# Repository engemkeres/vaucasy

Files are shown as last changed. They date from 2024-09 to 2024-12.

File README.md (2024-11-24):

# vaucasy
vaucasy is a split, ergonomic mechanical keyboard with a pair of OLEDs, rotary encoders and a trackball. It features a 4x7 staggered ortho layout on both halves.

The MCU chosen for this project was an STM32F401RET6, because I was familiar with STM32s F4 series.

[**QMK firmware**](https://github.com/engemkeres/qmk_firmware/tree/master/keyboards/vaucasy)

**Own firmware** with the support of ST's HAL library: [in progress](https://github.com/engemkeres/vaucasy_firmware)





**JCLPCB order preview:**

Right:
top_11_11_2024, 2_26_26 PM
bottom_11_11_2024, 2_26_26 PM

Left:
top_11_11_2024, 2_27_43 PM
bottom_11_11_2024, 2_27_43 PM

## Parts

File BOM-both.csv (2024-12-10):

Reference | Value | Datasheet | Footprint | Qty | DNP | JLCPCB part#
C1,C2,C3,C4,C5,C7,C13,C14,C15,C16,C17 | 100n | ~ | Capacitor_SMD:C_0402_1005Metric | 11 |  | C1525
C6 | 10u | ~ | Capacitor_SMD:C_0603_1608Metric | 1 |  | C19702
C8,C9 | 1u | ~ | Capacitor_SMD:C_0402_1005Metric | 2 |  | C52923
C10,C11 | 8p | ~ | Capacitor_SMD:C_0402_1005Metric | 2 |  | C1578
C12 | 4.7uF | ~ | Capacitor_SMD:C_0603_1608Metric | 1 |  | C19666
D1,D2,D3,D4,D5,D6,D7,D8,D9,D10,D11,D12,D13,D14,D15,D16,D17,D18,D19,D20,D21,D22,D23,D24,D25,D26,D27,D28,D29,D30,D31,D33 | Diode |  | ScottoKeebs_Components:Diode_SOD-123 | 32 |  | C7420318
F1 | 500mA | ~ | Fuse:Fuse_1206_3216Metric | 1 |  | C210357
J1 | USB_C | https://www.usb.org/sites/default/files/documents/usb_type-c.zip | Connector_USB:USB_C_Receptacle_HRO_TYPE-C-31-M-12 | 1 |  | C165948
J2 | OLED_128x32 |  | ScottoKeebs_Components:OLED_128x32 | 1 |  | C5248081
J4 | Trackball | ~ | Connector_PinHeader_2.54mm:PinHeader_1x05_P2.54mm_Vertical | 1
J5 | HC-05 BT | ~ | Connector_PinSocket_2.54mm:PinSocket_1x06_P2.54mm_Vertical | 1
J6 | DEBUG | ~ | Connector_PinHeader_2.54mm:PinHeader_1x04_P2.54mm_Vertical | 1
R1,R6,R7,R8 | 10k | ~ | Resistor_SMD:R_0402_1005Metric | 4 |  | C25744
R2 | 100R | ~ | Resistor_SMD:R_0402_1005Metric | 1 |  | C25076
R3,R4 | 5.1k | ~ | Resistor_SMD:R_0402_1005Metric | 2 |  | C25905
R9,R10,R13,R14 | 4.7k | ~ | Resistor_SMD:R_0402_1005Metric | 4 |  | C25900
S1,S2,S3,S4,S5,S6,S7,S8,S9,S10,S11,S12,S13,S14,S15,S16,S17,S18,S19,S20,S21,S22,S23,S24,S25,S26,S27,S28,S29,S30,S31 | Keyswitch | ~ | ScottoKeebs_Hotswap:Hotswap_Choc_V1V2_1.00u | 31
SW1 | SW_SPDT | ~ | Button_Switch_SMD:SW_SPDT_PCM12 | 1 |  | C221841
SW2 | SW_Push | ~ | ScottoKeebs_Components:Button_TL3342 | 1 |  | C115351
SW3 | RotaryEncoder_Switch | ~ | Rotary_Encoder:RotaryEncoder_Alps_EC11E-Switch_Vertical_H20mm | 1 |  | C470788
U1 | STM32F401RET6 | https://www.st.com/resource/en/datasheet/stm32f401re.pdf | Package_QFP:LQFP-64_10x10mm_P0.5mm | 1 |  | C116978
U2 | USBLC6-2SC6 | https://www.st.com/resource/en/datasheet/usblc6-2.pdf | Package_TO_SOT_SMD:SOT-23-6 | 1 |  | C2827654
U3 | XC6206 | https://www.torexsemi.com/file/xc6206/XC6206.pdf | Package_TO_SOT_SMD:SOT-23-3 | 1 |  | C5446
U4 | TRRS |  | ScottoKeebs_Components:TRRS_PJ-320A | 1 |  | C22459514
Y1 | 8MHz | ~ | Crystal:Crystal_SMD_3225-4Pin_3.2x2.5mm | 1 |  | C7275083

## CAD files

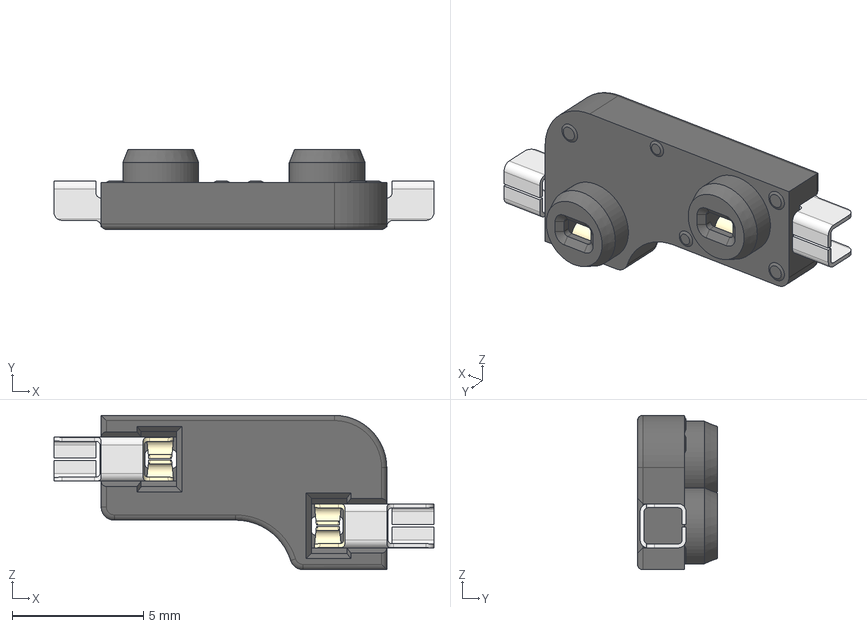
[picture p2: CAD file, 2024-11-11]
vaucasy_left/MX_V2/3D/MX-Hotswap-Socket.step
14.5 x 3.05 x 5.89 mm

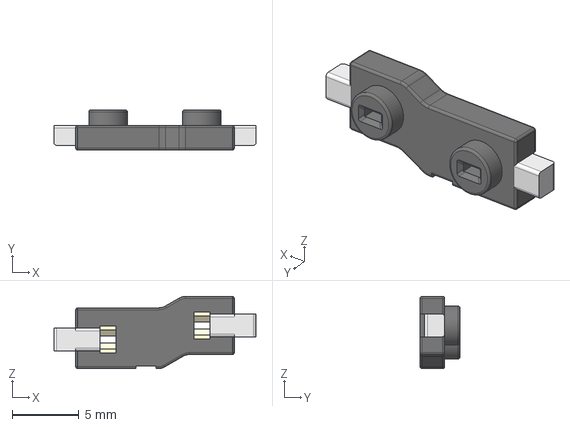
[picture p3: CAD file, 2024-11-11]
vaucasy_left/MX_V2/3D/Gateron-KS33-Socket.step
15.1 x 3.00 x 5.40 mm

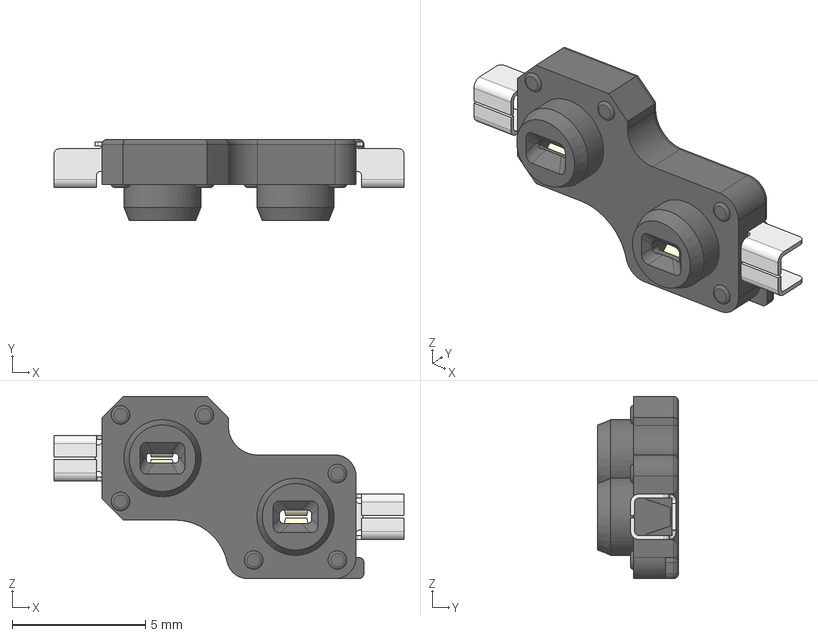
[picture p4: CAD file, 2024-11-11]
vaucasy_left/MX_V2/3D/Kailh-Choc-Socket-CPG135001S30.step
13.1 x 3.05 x 6.85 mm
Insert 2
Insert 1

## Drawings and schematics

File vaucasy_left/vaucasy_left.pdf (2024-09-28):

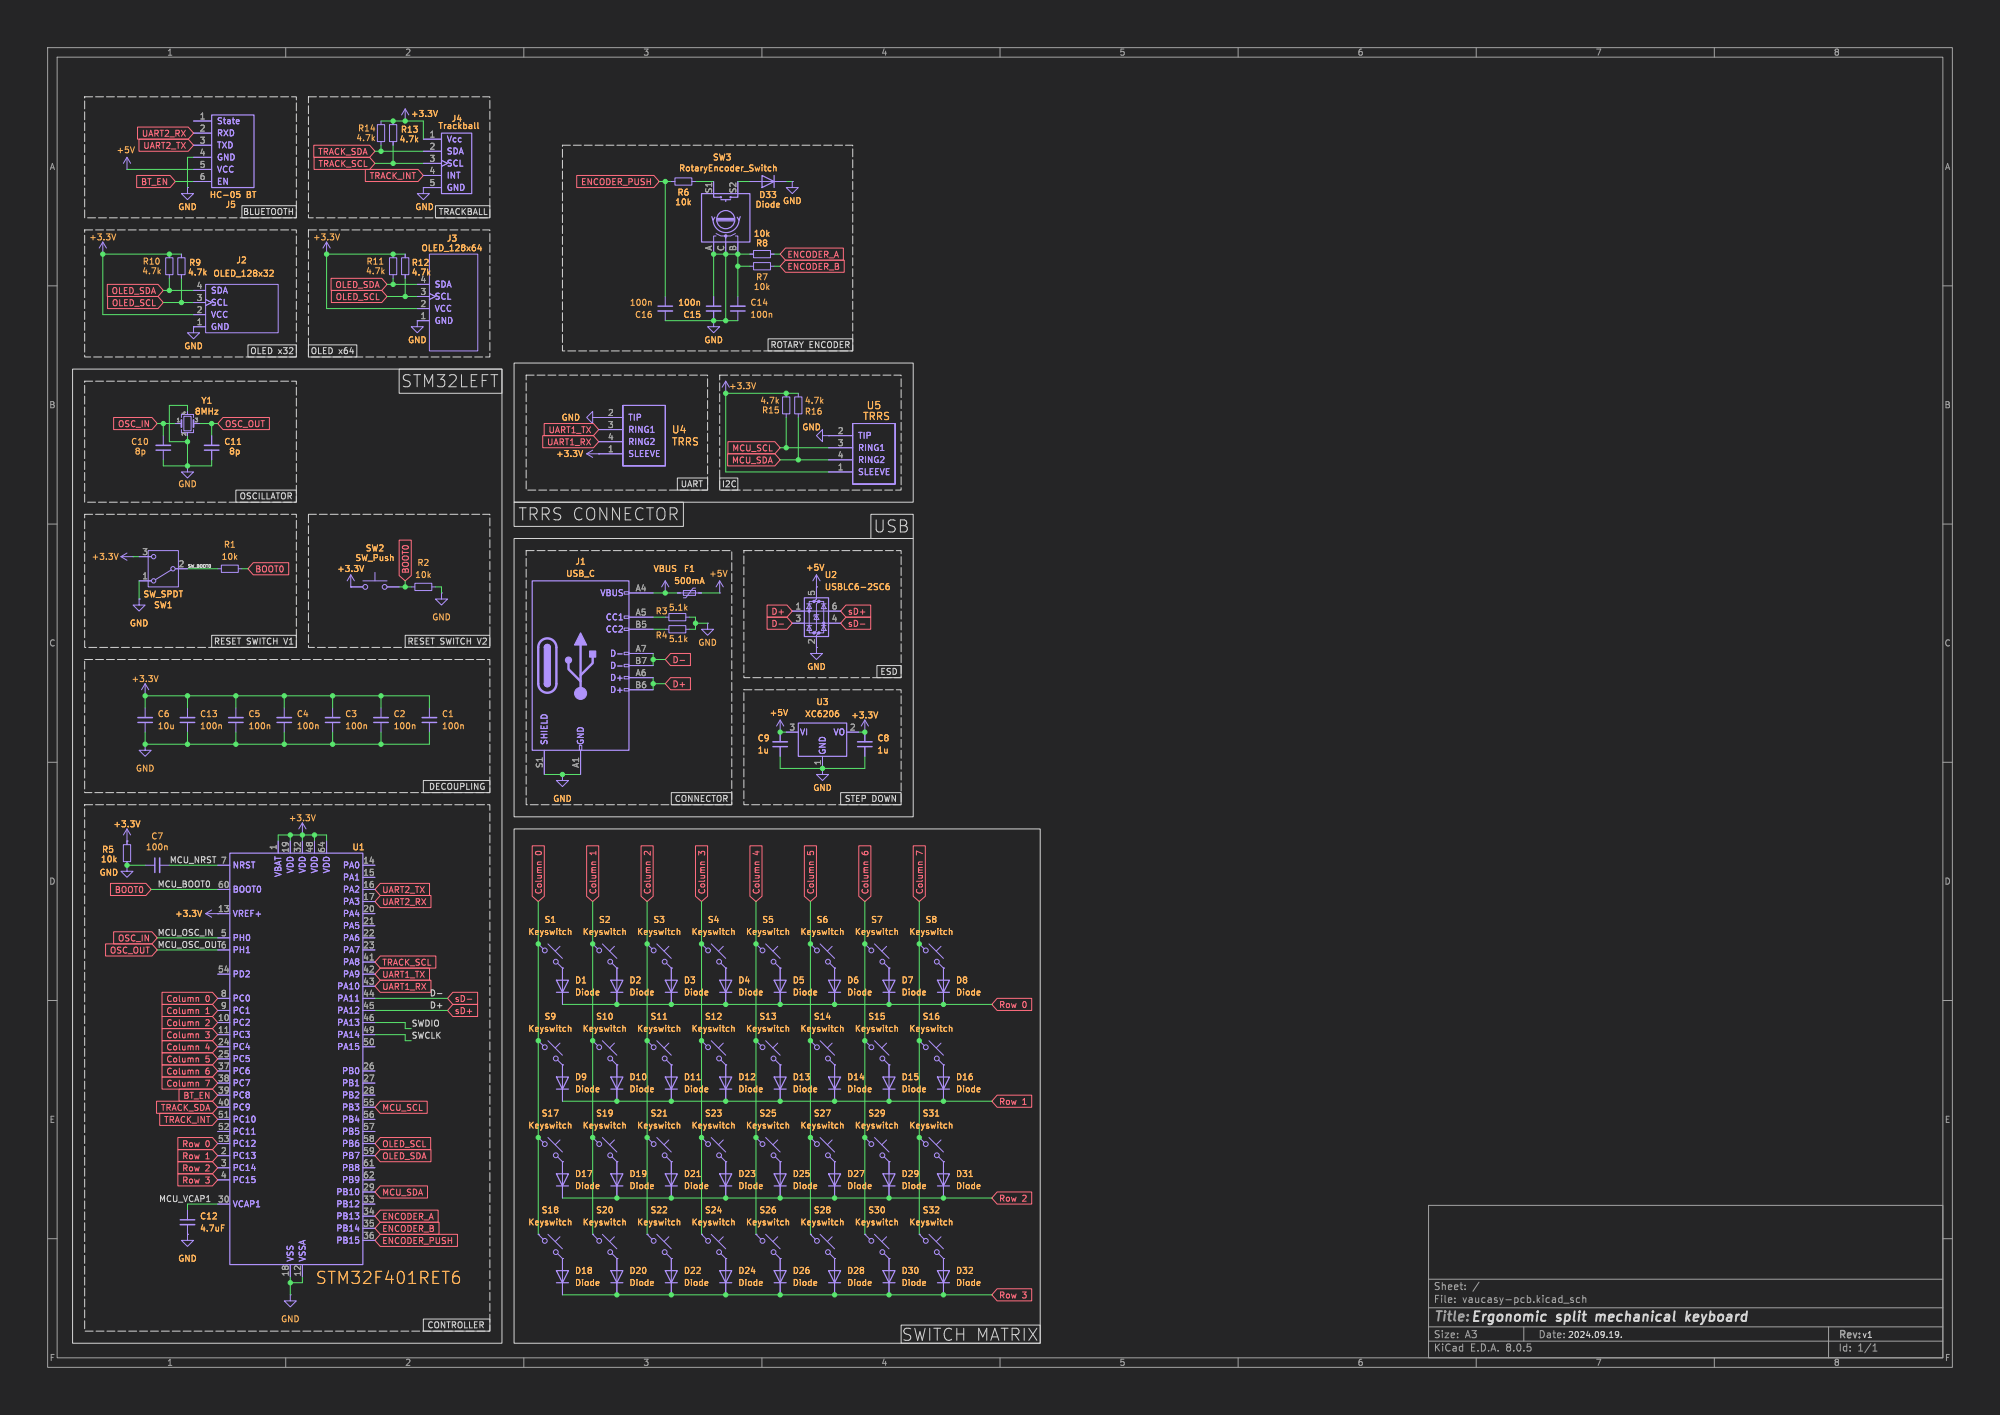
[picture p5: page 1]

J3 OLED_128x64 GND 1 VCC 2 SCL 3 SDA 4 +3.3V R13

Id: 1/1 Title: File: vaucasy-pcb.kicad_sch Sheet: / D9 Diode C6

D11 DiodeS12 Keyswitch D12 Diode D4 Diode D3 Diode D1 Diode

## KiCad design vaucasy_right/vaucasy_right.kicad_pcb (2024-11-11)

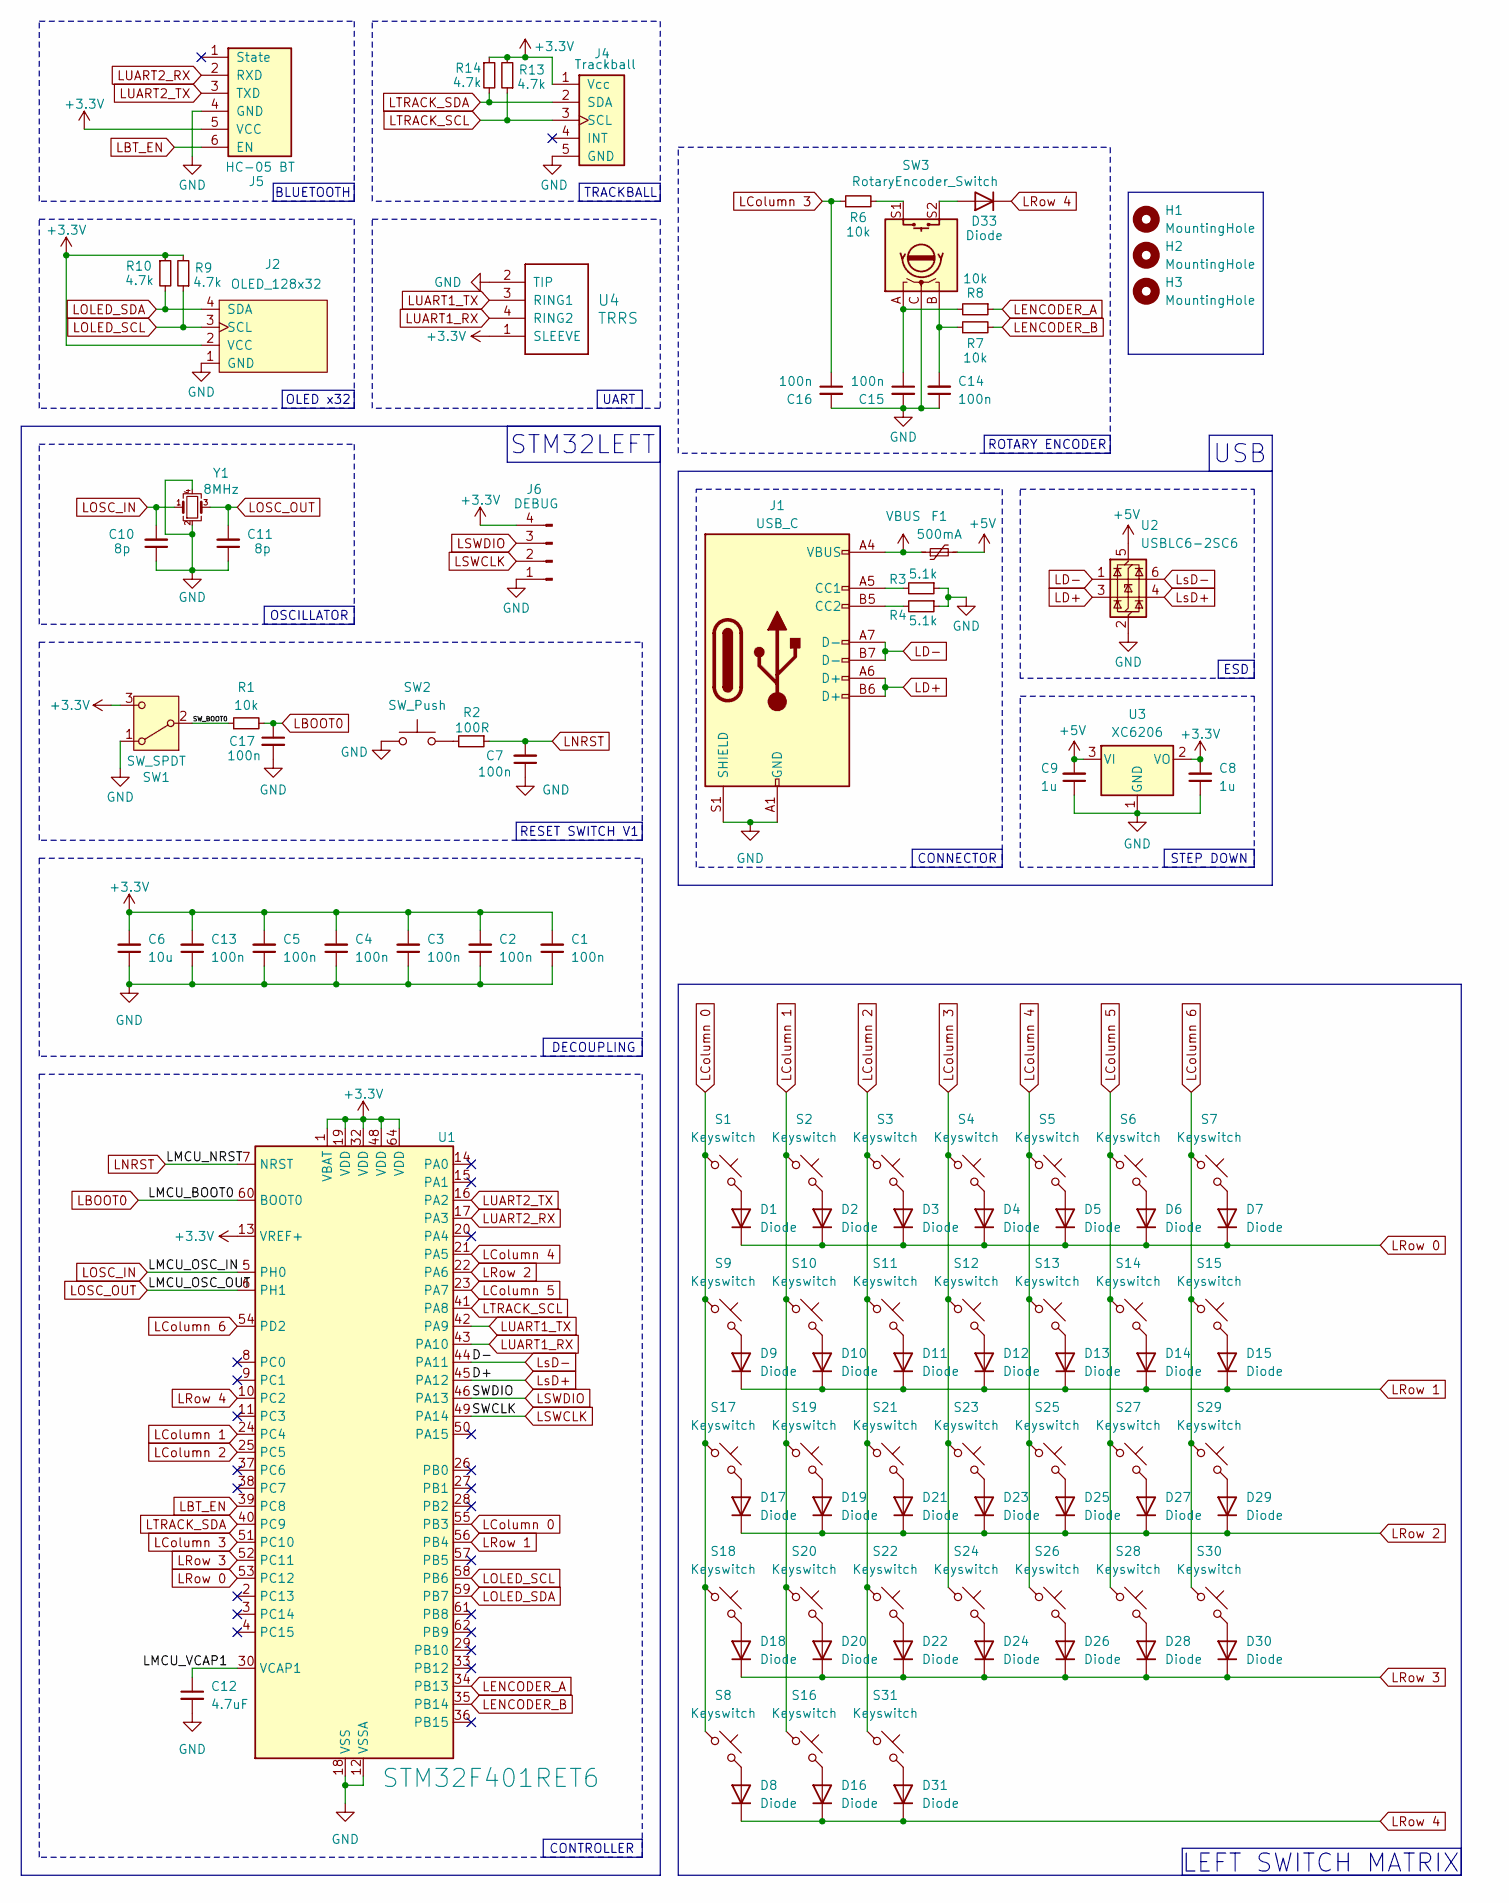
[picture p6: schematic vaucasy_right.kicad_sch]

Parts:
C1, C2, C3, C4, C5, C7, C13, C14, C15, C16, C17: 100n; C_0402_1005Metric
C6: 10u; C_0603_1608Metric
C8, C9: 1u; C_0402_1005Metric
C10, C11: 8p; C_0402_1005Metric
C12: 4.7uF; C_0603_1608Metric
D1, D2, D3, D4, D5, D6, D7, D8, D9, D10, D11, D12, D13, D14, D15, D16, D17, D18, D19, D20, D21, D22, D23, D24, D25, D26, D27, D28, D29, D30, D31, D33: Diode; Diode_SOD-123
F1: 500mA; Fuse_0603_1608Metric
H1, H2, H3: MountingHole; MountingHole_2.2mm_M2
J1: USB_C; USB_C_Receptacle_HRO_TYPE-C-31-M-12
J2: OLED_128x32
J4: Trackball; PinHeader_1x05_P2.54mm_Vertical
J5: HC-05 BT; PinSocket_1x06_P2.54mm_Vertical
J6: DEBUG; PinHeader_1x04_P2.54mm_Vertical
R1, R6, R7, R8: 10k; R_0402_1005Metric
R2: 100R; R_0402_1005Metric
R3, R4: 5.1k; R_0402_1005Metric
R9, R10, R13, R14: 4.7k; R_0402_1005Metric
S1, S2, S3, S4, S5, S6, S7, S8, S9, S10, S11, S12, S13, S14, S15, S16, S17, S18, S19, S20, S21, S22, S23, S24, S25, S26, S27, S28, S29, S30, S31: Keyswitch; Hotswap_Choc_V1V2_1.00u
SW1: SW_SPDT; SW_SPDT_PCM12
SW2: SW_Push; Button_TL3342
SW3: RotaryEncoder_Switch; RotaryEncoder_Alps_EC11E-Switch_Vertical_H20mm
U1: STM32F401RET6; LQFP-64_10x10mm_P0.5mm
U2: USBLC6-2SC6; SOT-23-6
U3: XC6206; SOT-23-3
U4: TRRS; TRRS_PJ-320A
Y1: 8MHz; Crystal_SMD_3225-4Pin_3.2x2.5mm

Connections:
+3.3V: C1.2, C2.2, C3.2, C4.2, C5.2, C6.2, C8.2, C13.2, J2.2 (VCC), J4.1 (Vcc), J5.5 (VCC), J6.4, R9.2, R10.1, R13.2, R14.1, SW1.3 (C), U1.1 (VBAT), U1.13 (VREF+), U1.19 (VDD), U1.32 (VDD), U1.48 (VDD), U1.64 (VDD), U3.2 (VO), U4.1 (SLEEVE)
+5V: C9.2, F1.2, U2.5 (VBUS), U3.3 (VI)
/LMCU_VCAP1: C12.1, U1.30 (VCAP1)
/SW_BOOT0: R1.1, SW1.2 (B)
GND: C1.1, C2.1, C3.1, C4.1, C5.1, C6.1, C7.1, C8.1, C9.1, C10.1, C11.1, C12.2, C13.1, C14.1, C15.2, C16.2, C17.2, J1.A1 (GND), J1.A12 (GND), J1.B1 (GND), J1.B12 (GND), J1.S1 (SHIELD), J2.1 (GND), J4.5 (GND), J5.4 (GND), J6.1, R3.1, R4.1, SW1.1 (A), SW2.1, SW3.C, U1.12 (VSSA), U1.18 (VSS), U1.31 (VSS), U1.47 (VSS), U1.63 (VSS), U2.2 (GND), U3.1 (GND), U4.2 (TIP), Y1.2, Y1.4
LBOOT0: C17.1, R1.2, U1.60 (BOOT0)
LBT_EN: J5.6 (EN), U1.39 (PC8)
LColumn 0: S1.1, S8.1, S9.1, S17.1, S18.1, U1.55 (PB3)
LColumn 1: S2.1, S10.1, S16.1, S19.1, S20.1, U1.24 (PC4)
LColumn 2: S3.1, S11.1, S21.1, S22.1, S31.1, U1.25 (PC5)
LColumn 3: C16.1, R6.1, S4.1, S12.1, S23.1, S24.1, U1.51 (PC10)
LColumn 4: S5.1, S13.1, S25.1, S26.1, U1.21 (PA5)
LColumn 5: S6.1, S14.1, S27.1, S28.1, U1.23 (PA7)
LColumn 6: S7.1, S15.1, S29.1, S30.1, U1.54 (PD2)
LD+: J1.A6 (D+), J1.B6 (D+), U2.3 (I/O2)
LD-: J1.A7 (D-), J1.B7 (D-), U2.1 (I/O1)
LENCODER_A: R8.1, U1.34 (PB13)
LENCODER_B: R7.2, U1.35 (PB14)
LNRST: C7.2, R2.1, U1.7 (NRST)
LOLED_SCL: J2.3 (SCL), R9.1, U1.58 (PB6)
LOLED_SDA: J2.4 (SDA), R10.2, U1.59 (PB7)
LOSC_IN: C10.2, U1.5 (PH0), Y1.1
LOSC_OUT: C11.2, U1.6 (PH1), Y1.3
LRow 0: D1.1 (K), D2.1 (K), D3.1 (K), D4.1 (K), D5.1 (K), D6.1 (K), D7.1 (K), U1.53 (PC12)
LRow 1: D9.1 (K), D10.1 (K), D11.1 (K), D12.1 (K), D13.1 (K), D14.1 (K), D15.1 (K), U1.56 (PB4)
LRow 2: D17.1 (K), D19.1 (K), D21.1 (K), D23.1 (K), D25.1 (K), D27.1 (K), D29.1 (K), U1.22 (PA6)
LRow 3: D18.1 (K), D20.1 (K), D22.1 (K), D24.1 (K), D26.1 (K), D28.1 (K), D30.1 (K), U1.52 (PC11)
LRow 4: D8.1 (K), D16.1 (K), D31.1 (K), D33.1 (K), U1.10 (PC2)
LSWCLK: J6.2, U1.49 (PA14)
LSWDIO: J6.3, U1.46 (PA13)
LTRACK_SCL: J4.3 (SCL), R13.1, U1.41 (PA8)
LTRACK_SDA: J4.2 (SDA), R14.2, U1.40 (PC9)
LUART1_RX: U1.43 (PA10), U4.4 (RING2)
LUART1_TX: U1.42 (PA9), U4.3 (RING1)
LUART2_RX: J5.2 (RXD), U1.17 (PA3)
LUART2_TX: J5.3 (TXD), U1.16 (PA2)
LsD+: U1.45 (PA12), U2.4 (I/O2)
LsD-: U1.44 (PA11), U2.6 (I/O1)
unnamed: C14.2, R7.1, SW3.B
unnamed: C15.1, R8.2, SW3.A
unnamed: D1.2 (A), S1.2
unnamed: D2.2 (A), S2.2
unnamed: D3.2 (A), S3.2
unnamed: D4.2 (A), S4.2
unnamed: D5.2 (A), S5.2
unnamed: D6.2 (A), S6.2
unnamed: D7.2 (A), S7.2
unnamed: D8.2 (A), S8.2
unnamed: D9.2 (A), S9.2
unnamed: D10.2 (A), S10.2
unnamed: D11.2 (A), S11.2
unnamed: D12.2 (A), S12.2
unnamed: D13.2 (A), S13.2
unnamed: D14.2 (A), S14.2
unnamed: D15.2 (A), S15.2
unnamed: D16.2 (A), S16.2
unnamed: D17.2 (A), S17.2
unnamed: D18.2 (A), S18.2
unnamed: D19.2 (A), S19.2
unnamed: D20.2 (A), S20.2
unnamed: D21.2 (A), S21.2
unnamed: D22.2 (A), S22.2
unnamed: D23.2 (A), S23.2
unnamed: D24.2 (A), S24.2
unnamed: D25.2 (A), S25.2
unnamed: D26.2 (A), S26.2
unnamed: D27.2 (A), S27.2
unnamed: D28.2 (A), S28.2
unnamed: D29.2 (A), S29.2
unnamed: D30.2 (A), S30.2
unnamed: D31.2 (A), S31.2
unnamed: D33.2 (A), SW3.S2
unnamed: J1.A5 (CC1), R3.2
unnamed: J1.B5 (CC2), R4.2
unnamed: R2.2, SW2.2
unnamed: R6.2, SW3.S1
VBUS: F1.1, J1.A4 (VBUS), J1.A9 (VBUS), J1.B4 (VBUS), J1.B9 (VBUS)

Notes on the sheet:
CONNECTOR
USB
TRACKBALL
UART
DECOUPLING
STM32LEFT
OSCILLATOR
ESD
CONTROLLER
OLED x32
STEP DOWN
BLUETOOTH
LEFT SWITCH MATRIX
RESET SWITCH V1
ROTARY ENCODER

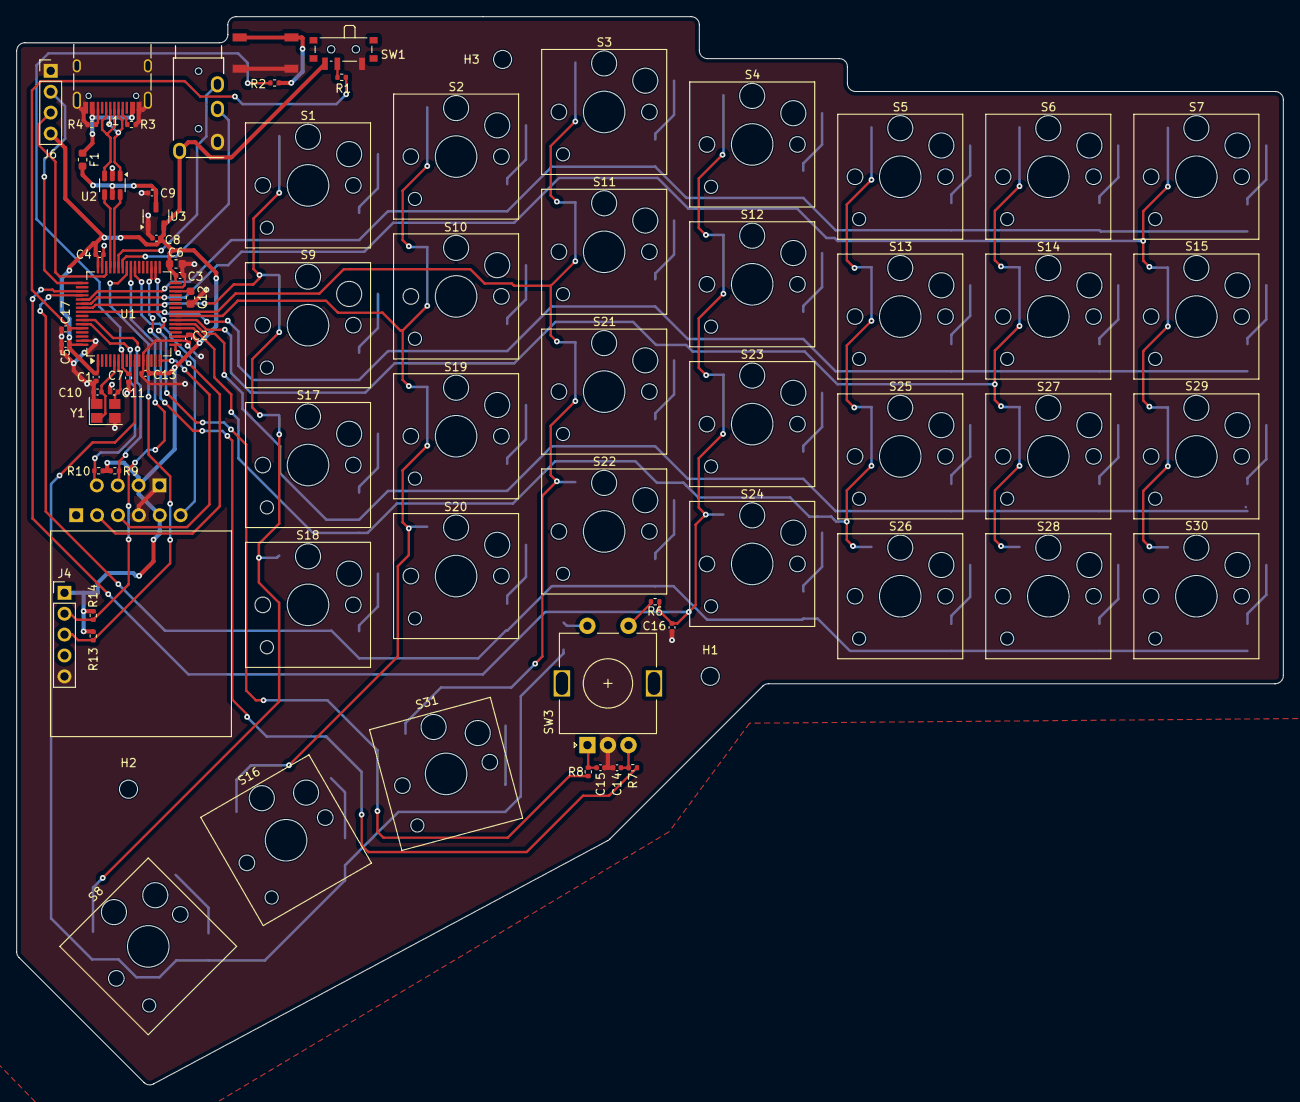
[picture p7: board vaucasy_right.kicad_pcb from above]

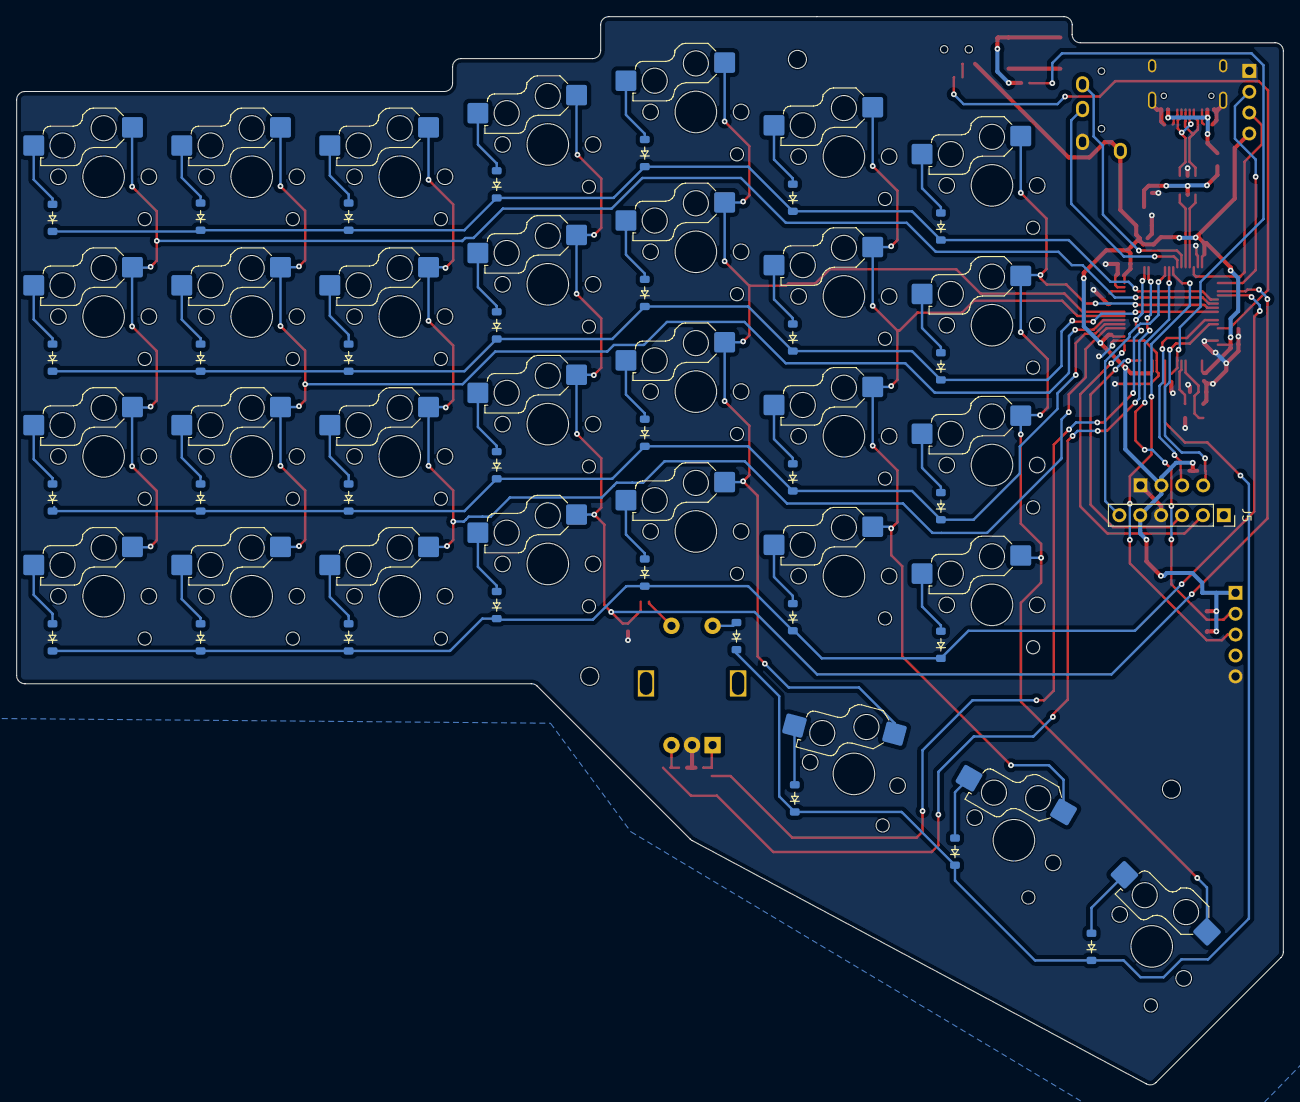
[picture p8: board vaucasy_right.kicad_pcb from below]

Board: 2 copper layers, 154.0 x 129.9 mm, 108 parts (33 on the bottom side), 77 nets.

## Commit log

2024-09-14 Initialize project
    [vaucasy-pcb.kicad_pcb, vaucasy-pcb.kicad_sch]
2024-09-14 Added MCU
    [vaucasy-pcb.kicad_sch]
2024-09-16 Switch matrix, connector and OLED added
    [vaucasy-pcb.kicad_sch]
2024-09-28 Schematic finished
    [vaucasy-pcb.kicad_sch]
2024-09-28 Started PCB layout
    [vaucasy-pcb.kicad_pcb, vaucasy-pcb.kicad_sch]
2024-10-03 Left side finished
    [vaucasy-pcb-B_Cu.gbr, vaucasy-pcb-B_Mask.gbr, vaucasy-pcb-B_Paste.gbr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]
2024-10-07 Track_INT added
    [vaucasy-pcb.kicad_pcb]
2024-10-07 DIrectory restructure
    [Gateron-KS33-Socket.step, Kailh-Choc-Socket-CPG135001S30.step, MX-Hotswap-Socket.step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]
2024-12-10 Bill of Materials
    JLCPCB order numbers
    [BOM-both.csv]
